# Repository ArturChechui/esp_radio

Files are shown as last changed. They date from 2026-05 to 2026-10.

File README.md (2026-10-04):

# ESP32 Internet Radio: From Zero to One

A fully custom-built, dual-core internet radio powered by an ESP32-S3, featuring zero-stutter I2S audio streaming, software DSP volume scaling, a custom 3D-printed acoustics enclosure, and a rock-solid FreeRTOS architecture.

---

## The Journey & The "Why"

This project was born out of a desire to build something complete from scratch: from the first soldered trace to the final line of modern C++ firmware.

After years of building complex embedded software systems and working through demanding release cycles, I took a step back during a career transition. I needed time to reset, evaluate relocation options and visa frameworks, and decide where to build my next chapter.

Alongside sorting out life's bigger questions, I wanted to re-arm my skillset and bridge the gap between pure software and physical hardware. Instead of letting this break go to waste, I used it to dive headfirst into hands-on hardware design, CAD modeling, and digital audio processing:

* **Hardware & Soldering:** Assembling microcontroller circuits, rotary encoders, and power stages from schematic to physical assembly.
* **CAD & Acoustic Engineering:** Designing custom enclosures in Fusion 360, tuning speaker chamber volumes using acoustic math, and FDM 3D printing.
* **Embedded System Architecture:** Writing thread-safe C++ firmware utilizing FreeRTOS tasks, lock-free ring buffers, I2S DMA pipelines, and efficient pointer-based DSP routines.

Today, this radio sits on my desk continuously playing my favorite Ukrainian stations. It is a warm piece of home, and a constant reminder that when life changes course, you can always build your own way forward.

---

## Evolution of the Build

| Phase | Development Log & Highlights |
| :--- | :--- |
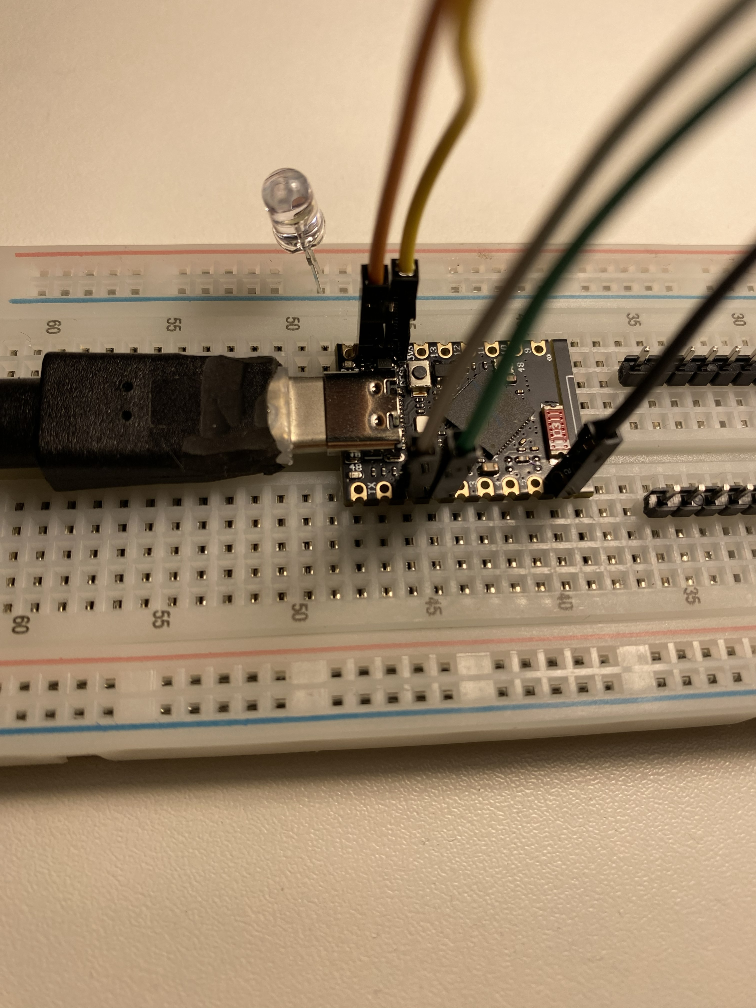
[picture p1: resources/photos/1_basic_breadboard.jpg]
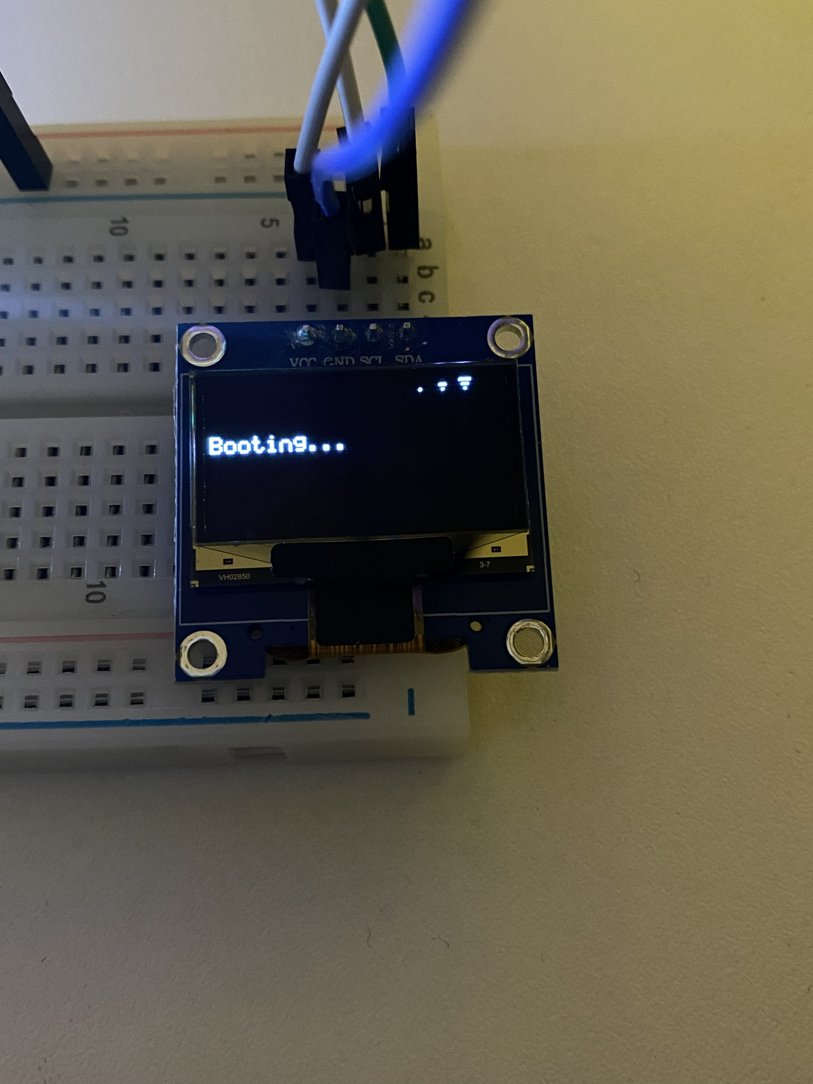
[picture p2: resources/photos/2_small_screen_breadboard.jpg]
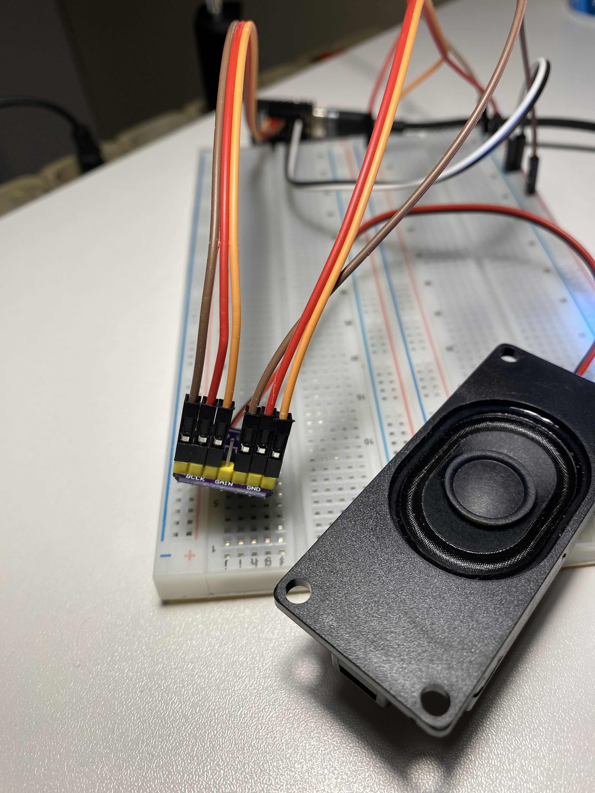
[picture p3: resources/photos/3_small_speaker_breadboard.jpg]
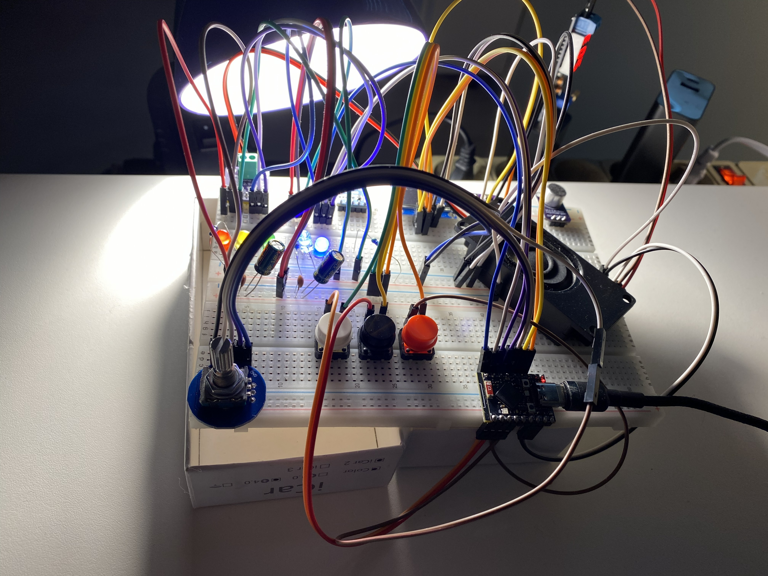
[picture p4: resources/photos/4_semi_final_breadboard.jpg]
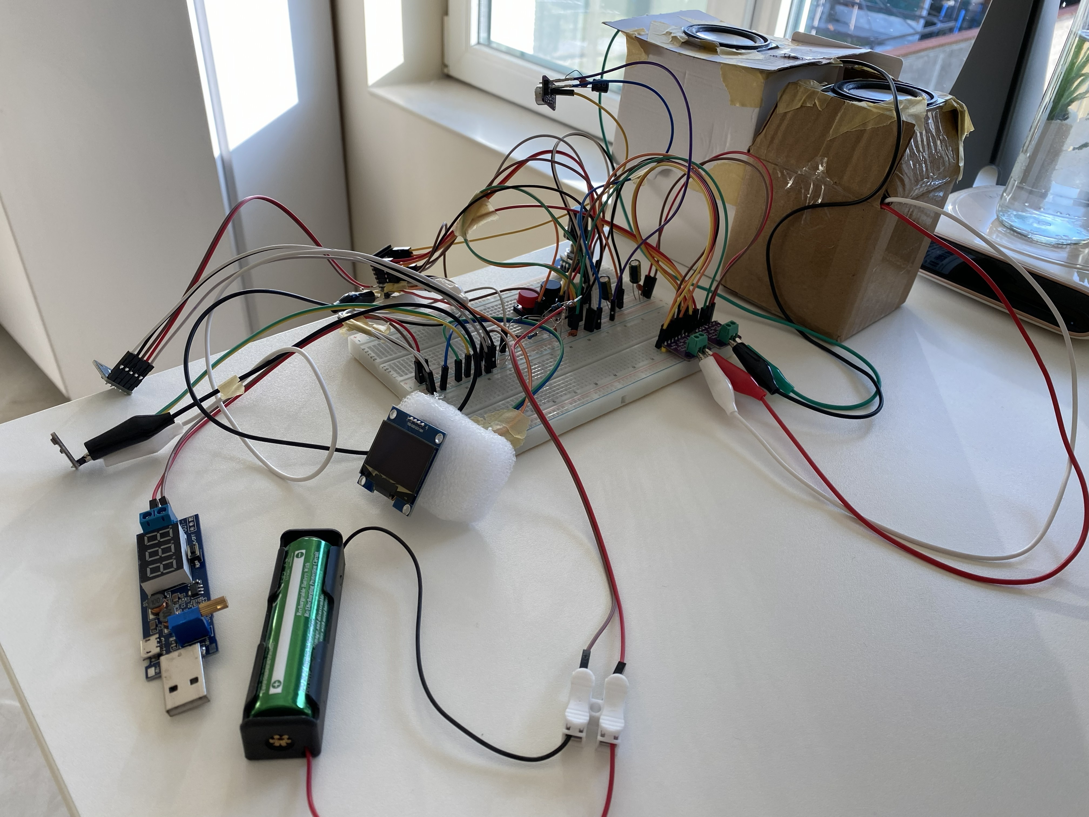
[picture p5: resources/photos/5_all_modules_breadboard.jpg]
| **1. Breadboard Prototyping** |      |
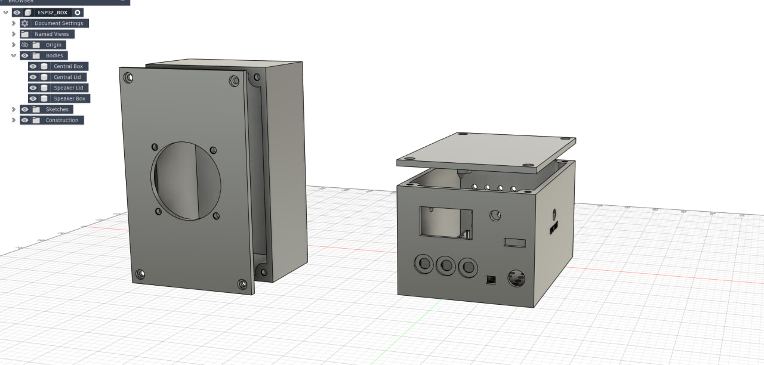
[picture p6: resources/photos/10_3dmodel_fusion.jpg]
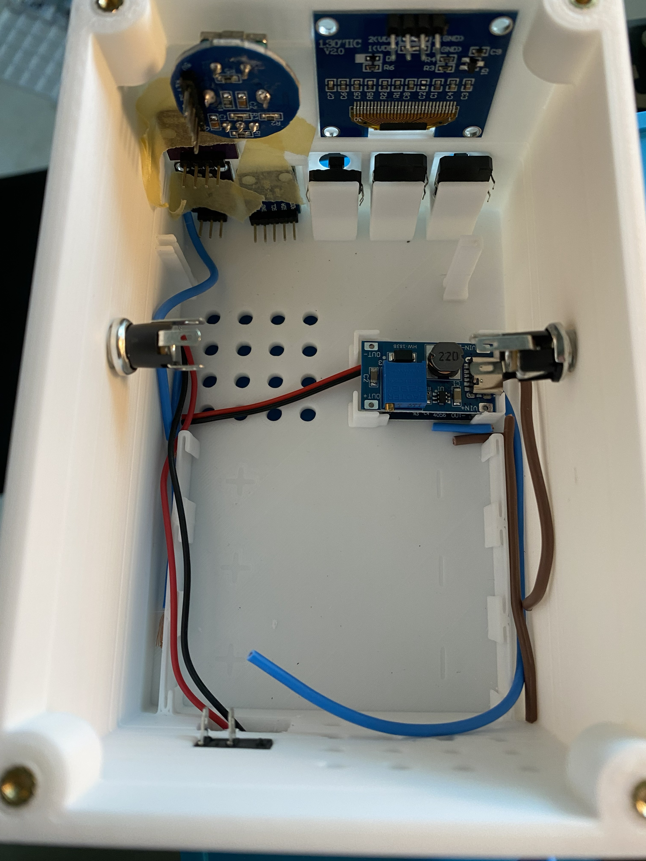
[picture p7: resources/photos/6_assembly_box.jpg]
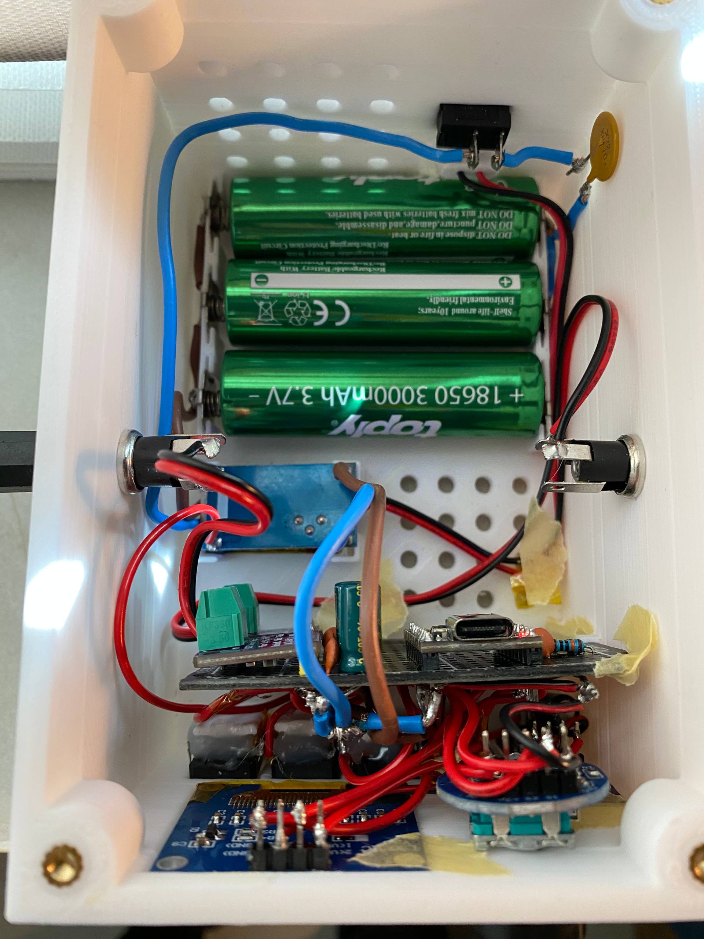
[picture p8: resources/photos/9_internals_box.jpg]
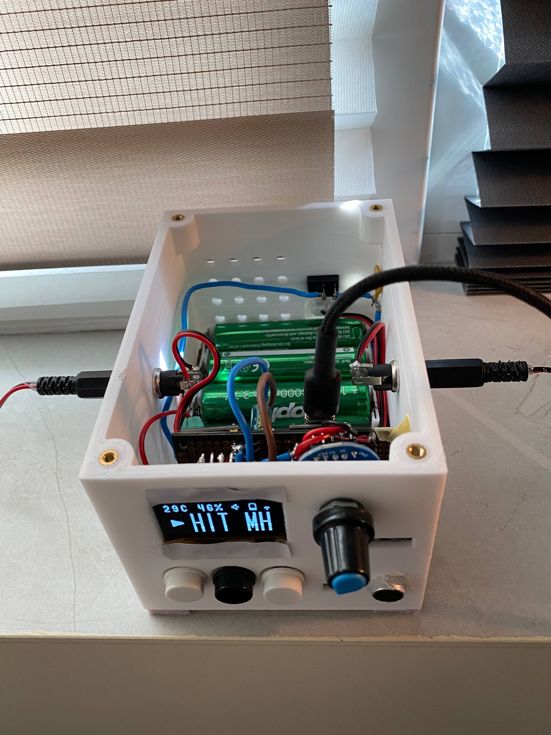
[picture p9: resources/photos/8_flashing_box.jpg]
| **2. Assembly & Flashing & 3D Modeling** | <br><br>   |
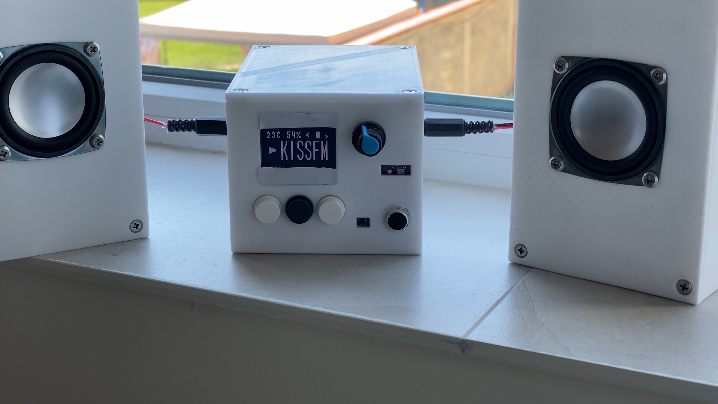
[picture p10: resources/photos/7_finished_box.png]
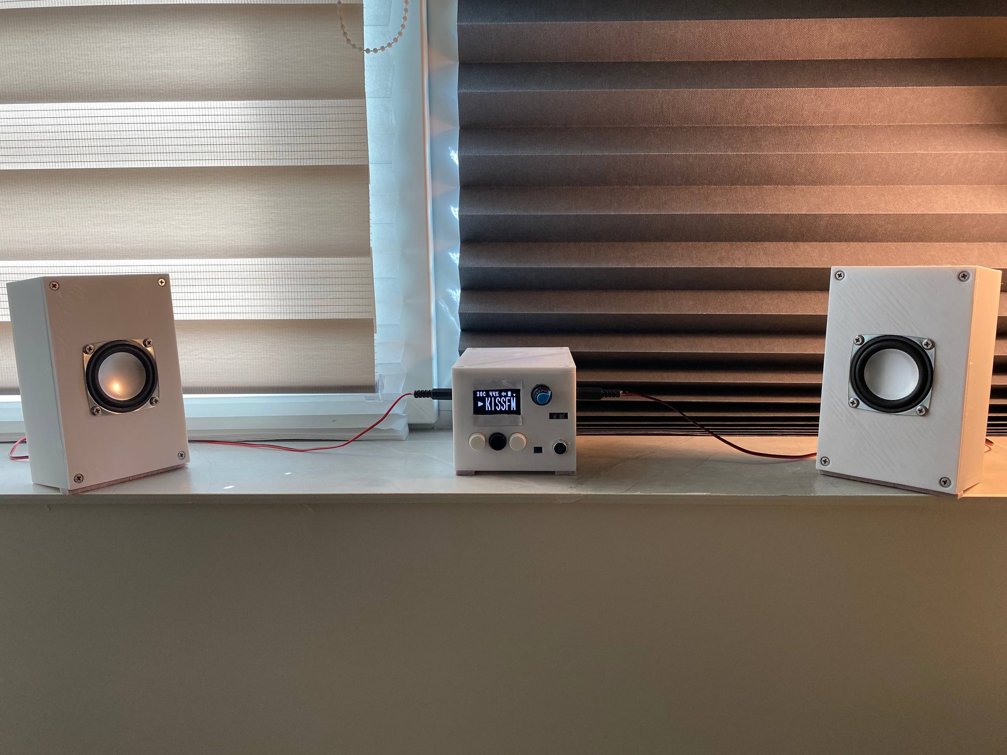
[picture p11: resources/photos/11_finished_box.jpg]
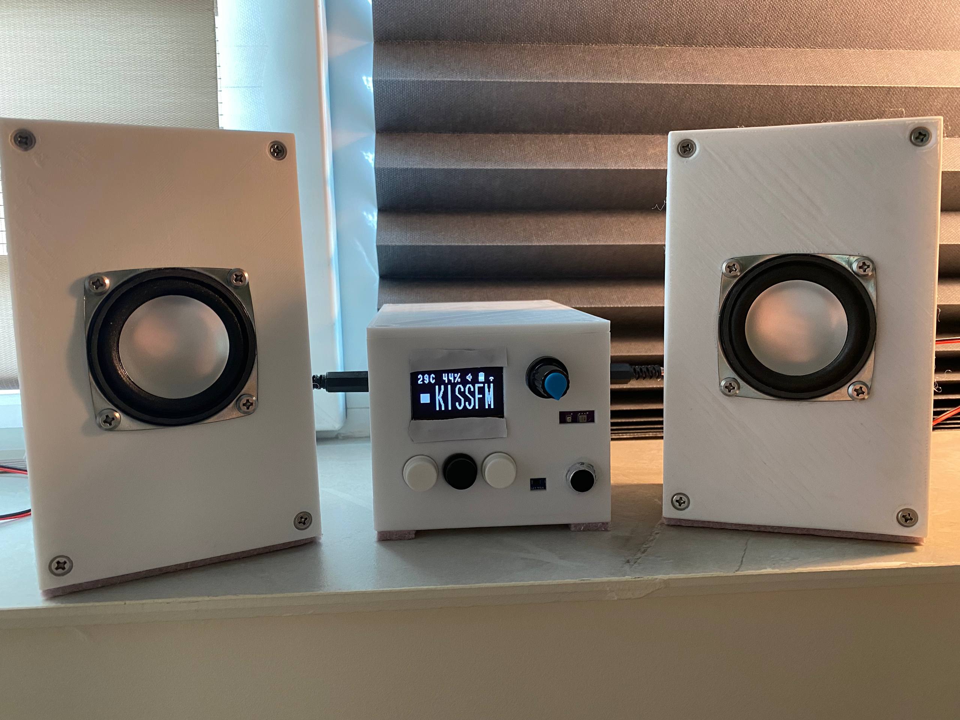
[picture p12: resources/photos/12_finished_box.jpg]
| **3. Final Product** |    |
---

## Feature Demonstrations

Below are recorded validation tests demonstrating the core features, real-time control loops, and network resilience of the radio pipeline.

### E2E Walkthroughs

* **Full Feature Walkthrough (v1):** Showcases station cycling, rotary control, and clap-to-play activation.

[▶ Click here or the image below to watch video](https://youtu.be/mcjk8brsLNs)

Watch the video (https://www.youtube.com/embed/mcjk8brsLNs)

* **Full Feature Walkthrough (v2):** Alternate routine verifying UI updates alongside hardware changes.

[▶ Click here or the image below to watch video](https://youtu.be/W9kkjmenZKo)

Watch the video (https://www.youtube.com/embed/W9kkjmenZKo)

### Network Resilience & Edge-Case Buffering

* **Low-RSSI Test (v1):** Stress test under extreme signal degradation (1-bar Wi-Fi where smartphones struggle to connect). Demonstrates the system detecting the drop, entering an explicit `Buffering` state, and successfully recovering the stream.

[▶ Click here or the image below to watch video](https://youtu.be/d_K3pIjVS1A)

Watch the video (https://www.youtube.com/embed/d_K3pIjVS1A)

* **Low-RSSI Test (v2):** Shows the stream recovery behavior and UI state synchronization under brutal packet-loss conditions.

[▶ Click here or the image below to watch video](https://youtu.be/vzDmDu5UXB0)

Watch the video (https://www.youtube.com/embed/vzDmDu5UXB0)

### Hardware Peripheral Validation

* **Station Skipping & Accumulation:** Tests the physical button debounce filters and fast station navigation logic.

[▶ Click here or the image below to watch video](https://youtu.be/VR3h5mVXo3s)

Watch the video (https://www.youtube.com/embed/VR3h5mVXo3s)

* **Rotary Encoder Step Control:** Verification of the quarter-detent accumulator algorithm providing linear audio attenuation.

[▶ Click here or the image below to watch video](https://youtu.be/cs2J7kylFnE)

Watch the video (https://www.youtube.com/embed/cs2J7kylFnE)

## Technical Overview

The system is designed to be modular, thread-safe, and resilient to network fluctuations.

### Acoustic & Enclosure Design

The enclosure isn't just a shell, it was engineered as a tuned acoustic chamber to maximize the performance of the drivers.

* **Custom "Golden Ratio" Geometry:** The design is based on the **Golden Ratio for Loudspeaker Enclosures** ($1 : 1.618 : 0.618$) to minimize internal standing waves and resonance.
* **Dimensional Adaptation:** To accommodate the physical depth of the high-performance speakers, the standard ratio was carefully adapted. The final outer dimensions are **145mm (W) x 90mm (H) x 55mm (D)**. With **4mm thick walls** for structural rigidity, the internal volume is optimized for the specific resonant frequency of the drivers.
* **Virtual Volume Enhancement:** The speaker chambers are filled with **Polyester Fiberfill**. This material slows down the air particles inside the box, tricking the speaker into "thinking" it is in a much larger enclosure. This provides a significantly richer sound and deeper bass response than a standard hollow 3D-printed box would allow.

### Software Stack

* **Language:** C++17
* **OS:** FreeRTOS (ESP-IDF)
* **Audio:** I2S protocol for external DAC communication and Q15 fixed-point DSP volume math.
* **Data:** JSON-based station management and system manifests.
* **Core Logic:** A custom `TaskRunner` system that manages background execution using atomic generation-tagged task handles to guarantee zero memory leaks and safe cooperative thread termination.

### Key Features

* **GitHub Station Sync:** By **long-pressing the Play button**, the radio automatically downloads the latest `stations.json` file directly from the main branch of the project's GitHub repository. To ensure data integrity, the system displays a status message and **blocks all physical inputs** for the 1-2 seconds it takes to perform the sync.
* **Clap-to-Play:** A fun, integrated feature that monitors the microphone for a specific sound profile, allowing the user to trigger playback with a simple clap.
* **WiFi Provisioning:** A dedicated setup mode allows the radio to host its own configuration portal, making it easy to connect to any local network without hardcoding credentials.
* **Tactile Volume Control:** Uses a rotary encoder with an accumulation algorithm (quarter-detent) to provide smooth, professional-feeling volume adjustment.
* **Dedicated Playback Buttons:** Physical buttons for **Play/Pause**, **Next**, and **Previous** stations for a "classic radio" feel that doesn't require looking at a screen.
* **OLED Interface:** A high-contrast display showing station names, real-time signal strength (RSSI), and system status icons.
* **Resilient Audio Pipeline:** A lock-free `RingBuffer` and producer/consumer `TaskRunner` architecture designed to handle network jitter and prevent audio "hiccups" during streaming.

---

## Lessons Learned

### Theory vs. Practice

The biggest takeaway from this project was the realization of the gap between theory and reality. In software, variables are usually controlled. In hardware, **everything is a variable.**

* **Signal Noise:** Real-world interference affects audio and sensor data in ways a simulator never shows.
* **Hardware Tolerance:** Components don't always behave exactly like the datasheet says.
* **Adaptability:** I learned that a good engineer doesn't just write a perfect plan; they write a plan that is flexible enough to survive the "real world."

---

## How it Works (Architecture)

1. **Network Layer:** Fetches MP3 streams via HTTP.
2. **Buffer Layer:** A thread-safe circular buffer (RingBuffer) stores raw bitstream data using fine-grained atomic memory order constraints.
3. **Decode Layer:** An MP3 decoder task pulls from the buffer and produces PCM samples using fast `minimp3` routines and pointer post-increment Q15 DSP scaling.
4. **Output Layer:** I2S pushes the stereo samples to the external DACs/speakers.
5. **Control Layer:** Monitors buttons and encoders to dispatch system-wide events.

---

## Hardware Components

- MCU: ESP32-S3 SuperMini
- Display: 1.3 inches SH1106 128x64 OLED via I2C
- Temp/Hum: AHT20 (I2C)
- Light sensor: BH1750 (I2C)
- Sound sensor: GY-MAX4466 (ADC)
- Audio modules: 2x MAX98357 (I2S DAC/amp)
- Speakers: 2x AIYIMA 2 inches 4 Ohms 3W
- Battery: 3x 18650 Li-ion, 3000 mAh each
- Inputs:
  - Buttons: Next, Previous, Play/Stop
  - Rotary encoder EC11 for Volume
- Case: Custom 3D-printed enclosure designed in Fusion 360

---

## Interactive Documentation & Release Specs

The full source code architecture, API references, and system design specifications are compiled and deployed online:

* **[Live Doxygen Documentation Portal](https://arturchechui.github.io/esp_radio/doxygen/html/index.html)**
* **[System Design Specifications (Requirements.md)](https://raw.githubusercontent.com/ArturChechui/esp_radio/refs/heads/main/docs/requirements.md)**

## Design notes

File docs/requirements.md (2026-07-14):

# ESP32 Internet Radio – Requirements

## 0. Summary

An ESP32-S3 based internet radio device that:

- Plays online radio streams (AAC + MP3) via ESP-ADF.
- Shows a station list on a 0.96" OLED (I2C) and indicates the currently active station.
- Uses buttons for selection + play/stop and a rotary encoder for volume.
- Displays temperature & humidity in a corner of the screen (AHT20).
- Reads ambient light and applies day/night input mode behavior.
- Monitors battery level and shows battery status in the UI.
- Maintains a local station list and supports on-demand sync from GitHub.

## 1. Goals & Non-Goals

### Goals

- Reliable playback of AAC/MP3 radio URLs.
- Predictable UI behavior: selection is separate from activation.
- Testable core logic (state machine, station selection, persistence rules).
- Safe station-list synchronization with manifest check and file swap.
- Integrated light, clap, and battery sensing modules.

### Non-Goals

- Metadata (ICY title/artist), album art, track history.
- Web UI / BLE UI for station management (beyond on-device sync).
- Audius / Spotify integration.

## 2. Hardware Configuration

- MCU: ESP32-S3 SuperMini
- Display: 1.3" SH1106 128x64 OLED via I2C
- Temp/Hum: AHT20 (I2C)
- Light sensor: BH1750 (I2C)
- Sound sensor: GY-MAX4466 (ADC)
- Audio modules: 2x MAX98357 (I2S DAC/amp)
- Speakers: 2x AIYIMA 2" 4 Ohms 3W
- Battery: 3x 18650 Li-ion, 3000 mAh each
- Inputs:
  - Buttons: Next, Previous, Play/Stop
  - Rotary encoder EC11 for Volume

## 3. Functional Requirements (FR)

### FR-01 Station list display

- The device shall display a list of stations.
- Next to 6 stations shall be visible at once.
- Station names shall be truncated if they exceed display width.

Acceptance:

- Device displays stations on screen.

### FR-02 Play

- `Play/Stop` button shall start playback of the currently selected station if stopped.

Acceptance:

- Given a reachable URL and Wi-Fi connected, audio starts within a reasonable time (informational target: P50 < 3s).

### FR-03 Stop

- Playback stops when `Play/Stop` is pressed during active playback.

Acceptance:

- Stop transitions to `Stopped` state and audio output ceases.

### FR-04 Active station indicator & navigation

- The selected station shall be marked with a playback status icon (Play, Stop, Buffering).
- `Next` shall increment to the next logical station in the list.
- `Previous` shall decrement to the previous logical station in the list.
- Selection wraps at list boundaries.
- Multiple rapid presses on `Next` or `Previous` shall quickly browse through station names on the UI without initializing the network stream or starting playback on each hop.

Acceptance:

- Pressing Next/Previous updates the selected station index and renders the text change within 50 ms.
- Rapidly pounding the navigation buttons updates the screen but does not trigger audio decoding errors or network thread crashes.

### FR-05 Volume control (rotary encoder)

- Rotating encoder changes volume.
- Volume range: 0..100 (step: 2 by default).
- Volume changes apply immediately.

Acceptance:

- Rotating encoder updates volume and shows it on UI within 100 ms.

### FR-06 Temp/Humidity display

- Read AHT20 periodically (e.g., every 10 seconds).
- Display current temperature and humidity in a small UI corner.

Acceptance:

- Temp/Hum values update periodically and do not disrupt playback.

### FR-07 Persistence (NVS)

Persist in NVS:

- `station_idx` (`uint32_t`): The active zero-based index of the currently selected radio station.
- `volume` (`uint32_t`, range `0..100`): The current system audio output level.
- `wifi_ssid` (`string`): The network service set identifier captured via provisioning.
- `wifi_password` (`string`): The network security key captured via provisioning.
- `micfeature` (`uint32_t`, `0` or `1`): The master toggle state for the acoustic clap-to-play trigger feature (`0` = disabled, `1` = enabled).
- `autoplay` (`uint32_t`, `0` or `1`): The saved playback intent status used to resume audio automatically upon network initialization (`0` = disabled, `1` = enabled).

Acceptance:

- Given an adjusted volume value $V$, after a hardware reset or brownout cycle, the system initializes and restores the audio output level exactly to $V$.
- Given a station switch to index $I$, after a complete system power cycle, the UI and audio components boot directly into station index $I$.
- Given a state toggle where `toggleClapFeature()` sets claps to active, after a device reboot, the `micfeature` value reads as `1` and the `UiService` correctly restores the 1-pixel bitwise top ledger line over the volume block.
- Given a successful network configuration cycle through the portal, the captured SSID and password must be successfully written to `wifi_ssid` and `wifi_password` respectively.
- Given a system reboot where `autoplay` evaluates to `1`, the orchestration layer (controller) shall automatically trigger audio playback of `station_idx` immediately after a successful Wi-Fi connection is established. If `autoplay` evaluates to `0`, the device shall remain in a connected but stopped idle state.

### FR-08 Wi-Fi configuration

- Device connects to Wi-Fi automatically on boot using stored credentials.
- Provisioning Portal: If credentials are missing or connection fails, the device shall host a local captive provisioning network portal.
- Input Constraints: The provisioning web UI portal shall explicitly denote that only Latin-based ASCII characters are supported for SSID and Passwords to prevent downstream configuration parsing corruption.

Acceptance:

- With valid credentials, device reaches `Connected` within 30s after boot.
- With invalid credentials/unavailable AP, device reaches `Disconnected` within 30s and UI remains usable.
- After a disconnect event, device retries and can return to `Connected` without reboot.

### FR-09 Station list storage (LittleFS)

- Device shall store the station list as `stations.json` in LittleFS.
- On boot, device shall load `stations.json` into RAM and use it for the whole session.
- Station list schema is JSON array of objects `{id,name,url}`.

Constraints:

- cap: 10 stations.

Acceptance:

- If `stations.json` exists and is valid, device loads it and displays stations in the UI.
- If `stations.json` is missing or invalid, device displays "No stations available" and playback cannot be started.
- If `stations.json` becomes valid on the next boot, station list is shown and playback becomes available.
- After loading, the in-RAM list remains unchanged until an explicit sync is completed (FR-11).

JSON schema:

```json
[
  {"id":"radio1_aac_h","name":"Radio 1 (AAC High)","url":"https://...aac"},
  {"id":"some_mp3","name":"Some MP3","url":"https://...mp3"}
]
```

Notes:

- Validation rules: non-empty `id/name/url`, url starts with `http://` or `https://`.
- IDs must be unique within the file.

### FR-10 Boot behavior

On boot, the device shall execute the following sequence:

1. Initialize UI: Show "Booting..." screen immediately.
2. Load NVS: Read `volume`, `station_idx`, and `micfeature` settings.
3. Load FS: Load `stations.json` from LittleFS into RAM.
4. Network Check & Route: Read `wifi_ssid` and `wifi_password`.
4.1 If valid/connected: Route to Main Screen, display station name from `station_idx`.
4.2 If missing/failed: Route to Provisioning Screen and display a small instruction and a QR code to the portal.

Acceptance:

- Happy Path: With valid credentials stored, the radio boots directly to the Main station screen without showing the provisioning portal.
- Fallback Path: If credentials are missing or connection fails, the radio automatically opens the captive portal and renders the QR code with an instruction.
- Missing Playlist: If `stations.json` is missing or corrupt, the UI displays a "No stations available" error and blocks playback actions.

### FR-11 Station list synchronization (GitHub, on-demand)

- A long press on `Play/Stop` (3 seconds) shall start station synchronization.
- While sync is active, UI shall switch to a dedicated sync screen and all user inputs shall be ignored.
- Sync flow:
  - Download remote `manifest.json`.
  - Compare local and remote manifest `version`.
  - If versions differ, download remote `stations.json`.
  - Validate downloaded station JSON using the same schema/rules as FR-09.
  - Stage to temporary files and replace live files.
  - Reload station repository in the running session (no reboot required).
- If manifest is unchanged, sync exits without replacing files.

Failure handling:

- On Wi-Fi/HTTP failure, parse error, validation failure, or swap failure:
  - keep current files unchanged
  - exit sync
  - return UI to main screen

Acceptance:

- Long press (`>=3s`) on `Play/Stop` triggers sync mode.
- During sync, button/encoder input does not start/stop playback and does not change station/volume.
- If manifest version is unchanged, `stations.json` is not downloaded.
- If manifest version changed and downloaded JSON is valid, `stations.json` and `manifest.json` are swapped and station list reloads immediately.
- On any sync error, app returns to main screen and previously valid files remain active.

Notes:

- Manifest comparison uses `version` as the primary key.
- URLs are hosted on GitHub raw content.

### FR-12 Logging (local)

- Device shall output logs to serial console (`idf.py monitor`) for debugging.
- Log level shall be configurable at build-time (default: INFO).
- Logs shall include key events: boot, Wi-Fi connect/disconnect, play/stop, and station list update result.

Acceptance:

- Serial logs contain boot message, Wi-Fi state changes, play/stop actions, and updater final outcome.
- Default build logs at INFO level; a debug build can enable more verbose logs.
- On failures (invalid station list, playback error), an ERROR log entry is produced.

### FR-13 Light, clap and power modules

- Device shall read ambient light periodically and expose a `LightLevelUpdate` event.
- Device shall read battery voltage and estimated percentage periodically and expose a `BatteryLevelUpdate` event.
- UI shall show battery state icon (low/mid/full).
- Device shall run clap detection logic utilizing a dedicated FreeRTOS processing task monitoring microphone input.
- A Long Press on the `Next` button shall invoke `toggleClapFeature()`, flipping the master setting (`mClapFeatureEnabled`).
- Execution calls to activate detection (`startClapDetection(true)`) shall be conditionally checked against the master user setting (`mClapFeatureEnabled`). If the feature is toggled off, the execution request is ignored.
- When the master clap feature is active, an event (`ClapFeatureStateChangedEvent`) shall notify the UI service, drawing a minimalist 1-pixel-thick bitwise notification overlay at the top edge of the volume status block icon.

Acceptance:

- Light sensor values are produced periodically and can drive day/night input behavior.
- Battery voltage/percent values are produced periodically and battery icon updates accordingly.
- Long-pressing `Next` successfully flips the master state, saves the new value to NVS, and triggers a UI redraw.
- The clap detection task only runs when playback is stopped and the master feature state is enabled. If the feature is disabled, the microphone task remains completely inactive.

## 4. Non-Functional Requirements (NFR)

- NFR-01 Reliability: no crashes during 4-hour playback soak.
- NFR-02 Responsiveness: button actions should feel instant (UI update < ~100 ms).
- NFR-03 Resource: station list stored in RAM; max 10 items.
- NFR-04 Observability: log levels configurable at compile-time (INFO default).

## 5. Testing Strategy

Host unit tests:

- Station selection rules
- Player state machine transitions
- Persistence rules (autoplay + last_station_id + volume debounce)
- Station sync decision logic (manifest comparison, validation, swap, reload)
- JSON validation
- Light, battery, and clap processing logic

Target/integration tests:

- Temp, Light, Battery read sanity
- Clap module trigger
- LittleFS read/write
- Basic playback smoke on ESP32-S3

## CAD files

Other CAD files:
resources/3dModel/esp32Box.f3d
resources/3dModel/esp32Box_v2.f3d

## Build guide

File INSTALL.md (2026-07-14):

# Installation Guide

This guide covers setting up a development environment on WSL (Ubuntu) to build, test, and flash the ESP32 firmware.

## 1. System Dependencies & WSL Setup

Ensure you are running an updated Ubuntu environment inside WSL, then install the required core build tools:

```bash
# Update system packages
sudo apt update && sudo apt upgrade -y

# Install core build dependencies
sudo apt install git wget flex bison gperf python3 python3-pip python3-venv \
                 cmake ninja-build ccache libffi-dev libssl-dev dfu-util libusb-1.0-0 gcovr -y

```

## 2. ESP-IDF Framework Installation (v6.0)

Clone the Esperessif IoT Development Framework and install the compilation toolchain tailored for the target hardware architecture:

```bash
# Create and navigate to the framework directory
mkdir -p ~/esp
cd ~/esp

# Clone the repository recursively
git clone -b release/v6.0 --recursive [https://github.com/espressif/esp-idf.git](https://github.com/espressif/esp-idf.git)
cd ~/esp/esp-idf

# Install compilation tools optimized for the ESP32-S3 chip
./install.sh esp32s3

# Add an environment shortcut alias to your bash configuration
echo "alias get_idf='. \$HOME/esp/esp-idf/export.sh'" >> ~/.bashrc

```

> 💡 **Usage:** Open a new terminal or run `source ~/.bashrc`. You can now load the ESP-IDF toolchain in any session by typing `get_idf`.

## 3. Project Dependencies & Unit Testing Tools

Navigate to your workspace directory to configure the external library manifests and install the host testing frameworks:

```bash
# Register component manifest dependencies
idf.py add-dependency "espressif/cjson"

# Install Google Test and Google Mock libraries for host-driven unit tests
sudo apt install libgtest-dev libgmock-dev

```

## 4. USB Device Passthrough (WSL)

To flash the device and monitor serial output directly from your WSL Ubuntu terminal, you must share the USB port from Windows using `usbipd`.

1. **On Windows** (Open PowerShell as Administrator):
```powershell
# Install the usbipd tool
winget install dorssel.usbipd-win

# List connected USB devices to find your ESP32 Bus ID (e.g., 4-1)
usbipd list

# Bind the device (only needed once)
usbipd bind --busid <BUSID>

# Attach the device to your running WSL instance
usbipd attach --wsl --busid <BUSID>

```

2. **On WSL (Ubuntu)**:
Grant your user account permission to read and write to serial devices without requiring `sudo`:
```bash
sudo usermod -aG dialout $USER

```

*(Note: You will need to restart your WSL terminal session for the group changes to take effect).*

## 5. Building, Flashing & Monitoring Logs

To build, flash, and debug the project, you can either use the raw ESP-IDF command-line interfaces or the convenient `./tools/build.sh` script included in the workspace root.

### Option A: Using the Build Script (Recommended)

Make sure the script has execution permissions:

```bash
chmod +x ./tools/build.sh

```

**Usage Commands:**

```bash
./build.sh        # Executes 'idf.py build'
./build.sh -u     # Compiles unit tests (host)
./build.sh -r     # Runs unit tests (compiles them first if needed)
./build.sh -f     # Flashes the target device
./build.sh -m     # Opens the serial monitor
./build.sh -F     # Performs a sequential flash + monitor run
./build.sh -c     # Executes 'idf.py fullclean'
./build.sh -h     # Displays helper usage details

```

### Option B: Using Native `idf.py`

If you prefer running commands manually, initialize your shell session and invoke the utilities:

```bash
# Initialize ESP-IDF environment variables
get_idf

# Build the project, flash it, and open the serial monitor in one go
idf.py build flash monitor

```

### Useful Monitor Keyboard Shortcuts

* **`Ctrl + ]`**: Exit the monitor and release the serial port.
* **`Ctrl + T` then `Ctrl + H**`: View the built-in ESP-IDF monitor help menu for advanced logging shortcuts.

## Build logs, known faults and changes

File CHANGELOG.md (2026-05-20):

# Changelog

All notable changes to the ESP32 Internet Radio project will be documented in this file. This project adheres to [Semantic Versioning](https://semver.org/spec/v2.0.0.html) (`MAJOR.MINOR.PATCH`).

---

## [1.0.0] - 2026-05-20

### Added

* **Features:** Initial implementation of station display, audio playback (play, stop, skip), and Wi-Fi provisioning portal (`03756e4`, `48f2040`).
* **UI Controls:** Added rotary encoder volume adjustments with partial display updates (`62ff459`, `ffdba7e`).
* **Sensors:** Added real-time temperature, humidity, battery level, light, and acoustic clap sensing modules (`1d083b5`, `46d2689`).
* **Documentation:** Added comprehensive hardware wiring maps, component layout overviews, and system class/adapter/command diagrams (`ced8f07`, `e4f9ef6`, `d16504b`, `2ad77b2`).
* **CI/CD:** Added automated build checks via `ci.yml` alongside initial project boilerplate (`5e75130`, `5c727b9`, `052dc31`).

### Changed

* **Station Navigation:** Optimized station switching logic to support fast scrolling without blocking the audio streaming pipeline (`f63e0e0`).
* **Clap Detection:** Gated the microphone processing loop behind a master feature toggle mapped to a long-press on the Next button (`f63e0e0`).
* **Captive Portal:** Refactored the provisioning layout to include explicit Latin character constraints and browser compatibility tips (`f63e0e0`).
* **Specifications:** Refined and updated `Requirements.md` to align style, phrasing, and storage keys with the physical codebase (`ef2fcec`, `5048ddb`, `f0faed3`).

### Fixed

* **Diagrams & Mapping:** Corrected errors in the original system class structures and physical GPIO wiring layouts (`561d167`, `2ad77b2`).

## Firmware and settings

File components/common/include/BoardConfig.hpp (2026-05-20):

/**
 * @file BoardConfig.hpp
 * @brief Centralized hardware pin and peripheral configuration.
 *
 * This file defines the GPIO assignments and hardware constants for the
 * ESP32-based internet radio, including display, audio, and sensor pins.
 */

#pragma once

#include <array>
#include <cstdint>

/**
 * @namespace common
 * @brief Contains shared system-wide constants, types, and configurations.
 */
namespace common {

// I2C Configuration
/** @brief GPIO pin used for the I2C Serial Clock (SCL). */
static constexpr int I2C_SCL_GPIO = 1;  // GP1
/** @brief GPIO pin used for the I2C Serial Data (SDA). */
static constexpr int I2C_SDA_GPIO = 2;  // GP2
/** @brief I2C bus frequency in Hertz. */
static constexpr uint32_t I2C_FREQ_HZ = 100000;  // TODO: test with 400000 later
/** @brief I2C slave address for the OLED display. */
static constexpr uint8_t OLED_I2C_ADDR = 0x3C;
/** @brief I2C slave address for the BH1750 ambient light sensor. */
static constexpr uint8_t Bh1750I2cAddr = 0x23;
// TODO: SH1106 usually needs a +2 column shift. Set to 0 if image appears horizontally shifted.
/** @brief Horizontal column offset required for the specific OLED controller. */
static constexpr uint8_t OLED_COLUMN_OFFSET = 2;

// I2S Configuration (audio output)
/** @brief GPIO pin for the I2S Bit Clock (BCLK). */
static constexpr uint8_t I2S_BCLK_GPIO = 6;
/** @brief GPIO pin for the I2S Left/Right Clock (LRCK / Word Select). */
static constexpr uint8_t I2S_LRCK_GPIO = 5;
/** @brief GPIO pin for the I2S Data Out (DOUT). */
static constexpr uint8_t I2S_DOUT_GPIO = 7;
/** @brief Target audio sample rate in Hertz. */
static constexpr uint32_t I2S_SAMPLE_RATE = 44100;

// Buttons
/** @brief GPIO pin for the "Next Station" button. */
static constexpr uint64_t ButtonNextGpio = 4;
/** @brief GPIO pin for the "Previous Station" button. */
static constexpr uint64_t ButtonPrevGpio = 10;
/** @brief GPIO pin for the "Play/Stop" toggle button. */
static constexpr uint64_t ButtonPlayStopGpio = 9;
/** @brief Array containing all managed button GPIOs for batch initialization. */
static constexpr std::array<uint64_t, 3> ButtonGpios = {
    ButtonPlayStopGpio,
    ButtonNextGpio,
    ButtonPrevGpio,
};
/** @brief GPIO pin for the first phase signal (S1) of the rotary encoder. */
static constexpr uint64_t EncS1Gpio = 13;
/** @brief GPIO pin for the second phase signal (S2) of the rotary encoder. */
static constexpr uint64_t EncS2Gpio = 12;

// Analog inputs
/** @brief GPIO pin assigned to the ADC channel for microphone input. */
static constexpr uint64_t MicAdcGpio = 8;
/** @brief GPIO pin assigned to the ADC channel for battery voltage sensing. */
static constexpr uint64_t BatteryAdcGpio = 3;

// Battery sensing divider: BAT+ -> R1 -> ADC -> R2 -> GND
/** @brief Resistance of the high-side resistor (R1) in the battery voltage divider. */
static constexpr uint32_t BatterySenseR1Ohm = 100000U;
/** @brief Resistance of the low-side resistor (R2) in the battery voltage divider. */
static constexpr uint32_t BatterySenseR2Ohm = 100000U;

}  // namespace common

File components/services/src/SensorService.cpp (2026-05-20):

#include "SensorService.hpp"

#include <esp_log.h>

#include <algorithm>
#include <array>
#include <cmath>

#include "BoardConfig.hpp"
#include "Events.hpp"
#include "IAdcReader.hpp"
#include "IClock.hpp"
#include "IEventQueue.hpp"
#include "II2cBus.hpp"
#include "IPersistentStorage.hpp"
#include "IPlayerService.hpp"
#include "IStopToken.hpp"
#include "ITaskRunner.hpp"

namespace services {
namespace {
constexpr const char* Tag = "SensorService";

constexpr uint16_t TaskStackWords = 6144;
constexpr uint16_t TaskPriority = 6U;
constexpr uint16_t TaskCore = 0U;

constexpr uint8_t Aht20Addr = 0x38;
constexpr uint8_t BusyBit = 0x80;
constexpr uint8_t CalibrationEnableBit = 0x08;

constexpr uint8_t Bh1750OneTimeHighResMode = 0x20;
constexpr uint32_t Bh1750MeasureWaitMs = 180U;

// Tuned for MAX4466 + ESP32 ADC in noisy environments.
constexpr uint32_t MicTaskSleepMs = 5U;
constexpr size_t ClapBurstSamples = 96U;  // TODO: make it more usable. try 64
constexpr int32_t ClapMinEnergyRaw = 16;
constexpr int32_t ClapMinPeakDiffRaw = 220;
constexpr int32_t ClapNoiseMultiplierNum = 5;
constexpr int32_t ClapNoiseMultiplierDen = 2;
constexpr int32_t ClapMinP2PRaw = 460;
constexpr int32_t ClapP2PToEnergyRatio = 6;
constexpr uint8_t ClapMinSamplesAboveThreshold = 1U;
constexpr uint32_t ClapCooldownMs = 300U;
constexpr uint32_t ClapArmDelayAfterPlaybackMs = 700U;
constexpr uint32_t ClapDiagLogPeriodMs = 300U;
constexpr uint32_t ClapTraceLogPeriodMs = 1500U;
constexpr int32_t NoiseEmaAlphaDiv = 32;

constexpr uint32_t FeatureDisabled = 0U;
constexpr uint32_t FeatureEnabled = 1U;
constexpr const char* ClapFeatureStorageKey = "micfeature";
}  // namespace

SensorService::SensorService(adapters::II2cBus& i2cBus, adapters::IAdcReader& adcReader,
                             common::IEventQueue& coreEventQueue, common::ITaskRunner& runner,
                             common::IClock& clock, adapters::IPersistentStorage& persistentStorage)
    : mI2cBus(i2cBus),
      mAdcReader(adcReader),
      mCoreEventQueue(coreEventQueue),
      mTaskRunner(runner),
      mClock(clock),
      mPersistentStorage(persistentStorage),
      mSensorTaskHandle(),
      mMicTaskHandle(),
      mIsAht20Inited(false),
      mMicNoiseMv(0),
      mClapFeatureEnabled(false),
      mShouldStartClapDet(false) {}

SensorService::~SensorService() {
    deinit();
}

bool SensorService::init() {
    if (!mAdcReader.setupChannel(common::MicAdcGpio)) {
        ESP_LOGE(Tag, "Failed to setup mic channel");
        return false;
    }

    if (!mAdcReader.setupChannel(common::BatteryAdcGpio)) {
        ESP_LOGE(Tag, "Failed to setup battery channel");
        return false;
    }

    mSensorTaskHandle = mTaskRunner.start(
        common::TaskParams{.name = "SensorTask", .priority = TaskPriority, .core = TaskCore},
        TaskStackWords, &SensorService::readStepFn, this);
    if (!mSensorTaskHandle.isValid()) {
        ESP_LOGE(Tag, "Failed to create SensorTask");
        return false;
    }

    uint32_t res = FeatureDisabled;
    if (!mPersistentStorage.getU32(ClapFeatureStorageKey, res)) {
        ESP_LOGW(Tag, "Failed to load ClapFeatureStorageKey, using default: disabled");
        res = FeatureDisabled;
    }
    mClapFeatureEnabled = (res != FeatureDisabled);

    if (mClapFeatureEnabled) {
        mMicTaskHandle = mTaskRunner.start(
            common::TaskParams{.name = "MicTask", .priority = TaskPriority, .core = TaskCore},
            TaskStackWords, &SensorService::listenStepFn, this);
        if (!mMicTaskHandle.isValid()) {
            ESP_LOGE(Tag, "Failed to create MicTask");

            (void)mTaskRunner.stop(mSensorTaskHandle, 7000);
            mSensorTaskHandle.reset();

            return false;
        }
    }

    return true;
}

void SensorService::deinit() {
    if (mMicTaskHandle.isValid()) {
        (void)mTaskRunner.stop(mMicTaskHandle, 7000);
        mMicTaskHandle.reset();
    }

    if (mSensorTaskHandle.isValid()) {
        (void)mTaskRunner.stop(mSensorTaskHandle, 7000);
        mSensorTaskHandle.reset();
    }
}

void SensorService::startClapDetection(const bool shouldStart) {
    mShouldStartClapDet = shouldStart;

    if (mClapFeatureEnabled && mShouldStartClapDet) {
        if (mMicTaskHandle.isValid()) {
            return;  // Already listening
        }

        ESP_LOGI(Tag, "startClapDetection: Starting clap detection in 100 ms...");
        mClock.sleepMs(100);
        mMicTaskHandle = mTaskRunner.start(
            common::TaskParams{.name = "MicTask", .priority = TaskPriority, .core = TaskCore},
            TaskStackWords, &SensorService::listenStepFn, this);
        if (!mMicTaskHandle.isValid()) {
            ESP_LOGE(Tag, "Failed to create MicTask");
        }
    } else {
        if (!mMicTaskHandle.isValid()) {
            return;  // Already stopped
        }

        ESP_LOGI(Tag, "startClapDetection: Stopping clap detection...");
        (void)mTaskRunner.stop(mMicTaskHandle, 2000);
        mMicTaskHandle.reset();
        mMicNoiseMv = 0;
    }
}

bool SensorService::toggleClapFeature() {
    mClapFeatureEnabled = !mClapFeatureEnabled;

    const auto val = mClapFeatureEnabled ? FeatureEnabled : FeatureDisabled;
    if (!mPersistentStorage.setU32(ClapFeatureStorageKey, val)) {
        ESP_LOGW(Tag, "Failed to set ClapFeatureStorageKey");
    }

    // when the feature is disabled, we need to stop the clap detection right away.
    // when the feature is enabled and the playback is stopped, we should start it.
    // So we retry the last known value of the client's intent.
    startClapDetection(mShouldStartClapDet);

    return mClapFeatureEnabled;
}

common::StepResult SensorService::listenStepFn(void* arg, common::IStopToken& token) {
    auto* self = static_cast<SensorService*>(arg);
    if (!self) {
        return {.action = common::StepAction::Error};
    }

    return self->listenStep(token);
}
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

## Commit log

2026-02-09 feat: add play, stop, skips and partially wifi (refs #2 #3 #4 #8)
    - Added functionality to play, stop and skip internet radio stations;
    - Adapted other classes to the new approach with Events;
    - Added tests for PlayerService;
    - Updated tests for other units that were failing;
    - Added minimp3 lib to be used as a decoder for PlayerService;
    - Added buttons implementation to be able to test Play and Stop;
    - Added Up/Down impl (early but it was a few lines);
    - Added WiFi configuration with a "secret" file;
    - Added more logs to see CPU and RAM loads;
    - Updated StationRepo to be the unit that holds all info about + actions with stations (curr, next, prev) , not only storage of them;
    [partitions.csv]
2026-02-09 feat: add play, stop, skips and partially wifi (refs #2 #3 #4 #8) (#15)
    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
    [partitions.csv]
2026-02-14 feat: add new ui with partial updates (refs #4) (#16)
    - Changed layout of UI: status bar + curr station + playback status;
    - Refactored UiService, Display + I2cBus to be able make partial updates;
    - Added processing of wifi, temp, station and playback status events on UI;
    - Improved common;
    - Added png for all the UI objects;
    - Added sequence diagram for Ui;
    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
2026-02-16 feat: add rotary encoder handling for volume (refs #5) (#17)
    - Added a common queue that supports ISR push;
    - Refactored GpioInput and InputService;
    - Renamed Up/Down to Next/Prev;
    - Moved clock to common;
    - Added volume icons in png and bytes;
    - Integrated volume icon to the UI;
    - Updated unit tests;
    - Corrected and regenerated some letters;
    [BoardConfig.hpp, GpioInput.cpp]
2026-02-18 feat: display temperature and humidity (refs #6) (#18)
    - Added mutex to i2c bus to use from different threads;
    - Added SensorService to trigger measurements from AHT20;
    - Fixed stopRequested in InputService;
    - Added seq diagram of the temp/hum read and display;
    - Added ut for SensorService;
    [I2cBus.cpp, SensorService.cpp]
2026-03-27 feat: add remaining features (refs #20, #11, #10, #9, #8, #7) (#19)
    - Added PersistentStorage to save wifi creds and last session state;
    - Added FileSystem to work with local files to load stations;
    - Added restoration of last session states in all requires services;
    - Added LongPress of PlayStop button;
    - Added "SyncStations" functionality;
    - Added log configuration;
    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
    [esp32Box.f3d]
2026-05-20 feat: optimize station navigation, gate claps, and update documentation (refs #24) (#25)
    - Decoupled navigation from playback for fast station skipping.
    - Added master toggle for clap detection on Next button long press.
    - Rendered 1-pixel bitwise line indicator over volume icon.
    - Added Latin charset and Safari browser recommendations to captive portal.
    - Documented system interfaces, variables, and events using Doxygen.
    - Aligned Requirements.md spec with current NVS storage keys and boot behaviors.
    [AudioBufferStats.hpp, BoardConfig.hpp]
2026-07-14 feat: implement autoplay, migrate to IDF v6 (refs #31 #28 #29) (#30)
    - Integrated autoplay functionality;
    - Adapted code for IDF v6;
    - Fixed startup volume issue;
    - Added INSTALL.md file;
    - Added a new 3d model of the box without battery + updated front panel;
    - Added LICENSE file;
    [esp32Box_v2.f3d]
